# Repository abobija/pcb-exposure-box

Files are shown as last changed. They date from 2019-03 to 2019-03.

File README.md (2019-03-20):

# pcb-exposure-box
PCB Exposure Box made of an old Scanner

When you set the timer (max 999 seconds) with UP/DOWN buttons and then press button START, micro-controller-unit (MCU) PIC16F84A will turn on light and start to countdown to zero. When timer comes to zero, MCU will turn off the light signaling via the piezzo speaker that exposure process is done.

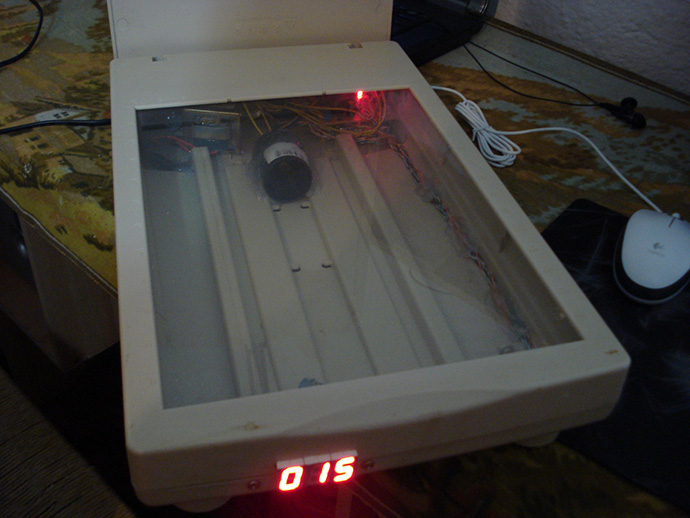
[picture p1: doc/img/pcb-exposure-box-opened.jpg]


# Video presentation

Click [here](https://www.youtube.com/watch?v=MrX0DLpo7UE) to watch short video presentation on YouTube.

_Video was recorded back in 2013 and quality of video is very bad (sorry about that)._

# Development Environment

- MCU used for realization of this project is PIC16F84A and software for them was written in C using (and compiled with) [mikroC environment](https://www.mikroe.com/mikroc-pic)
- PCBs were designed using the [Eagle](https://www.autodesk.com/products/eagle/overview)

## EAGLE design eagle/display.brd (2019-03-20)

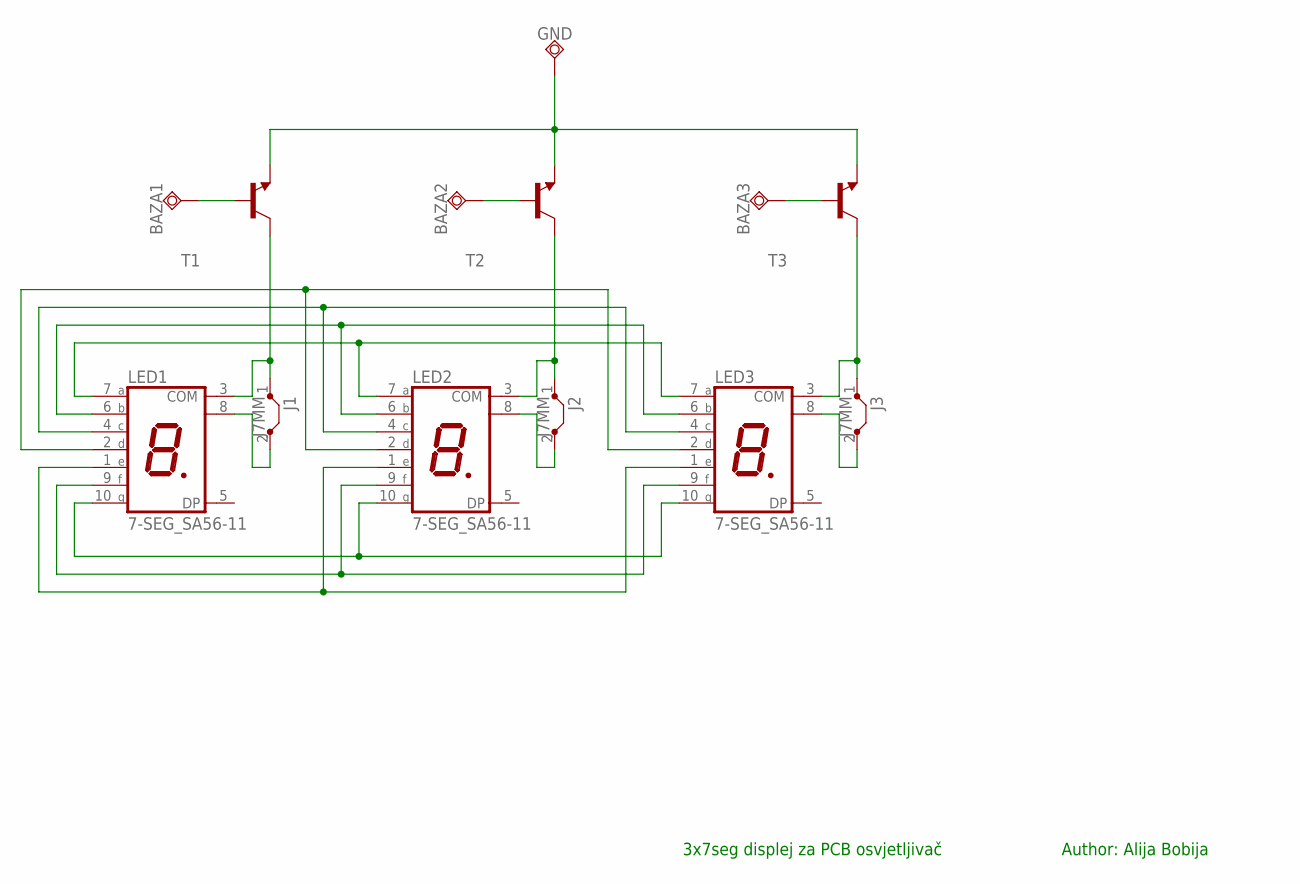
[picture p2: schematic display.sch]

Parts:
BAZA1, BAZA2, BAZA3: TPSQTP20SQ; TP20SQ
GND: TPSQTP20SQ; TP20SQ
J1, J2, J3: J7MM; 07
LED1, LED2, LED3: 7-SEG_SA56-11; SA56-11
T1, T2, T3: -NPN-SOT23-EBC; SOT23-EBC

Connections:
unnamed: LED1.7 (A), LED2.7 (A), LED3.7 (A)
unnamed: LED1.10 (G), LED2.10 (G), LED3.10 (G)
unnamed: LED1.6 (B), LED2.6 (B), LED3.6 (B)
unnamed: LED1.9 (F), LED2.9 (F), LED3.9 (F)
unnamed: LED1.4 (C), LED2.4 (C), LED3.4 (C)
unnamed: LED1.1 (E), LED2.1 (E), LED3.1 (E)
unnamed: LED1.2 (D), LED2.2 (D), LED3.2 (D)
unnamed: J1.1, LED1.3 (COM), T1.C
unnamed: J1.2, LED1.8 (COM)
unnamed: J2.1, LED2.3 (COM), T2.C
unnamed: J2.2, LED2.8 (COM)
unnamed: J3.1, LED3.3 (COM), T3.C
unnamed: J3.2, LED3.8 (COM)
unnamed: BAZA1.TP, T1.B
unnamed: BAZA2.TP, T2.B
unnamed: BAZA3.TP, T3.B
unnamed: GND.TP, T1.E, T2.E, T3.E

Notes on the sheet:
Author: Alija Bobija
3x7seg displej za PCB osvjetljivač

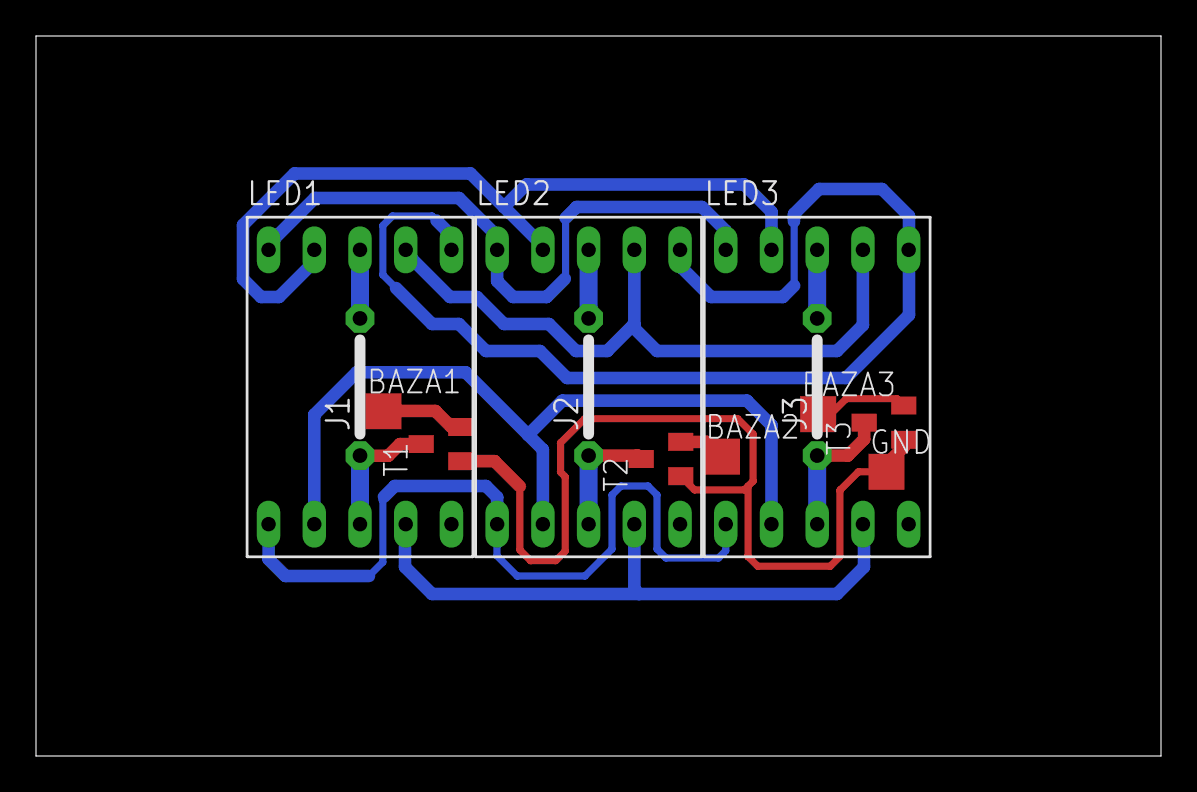
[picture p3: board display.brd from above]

Board: 2 copper layers, 62.5 x 40.0 mm, 13 parts (0 on the bottom side), 17 nets.

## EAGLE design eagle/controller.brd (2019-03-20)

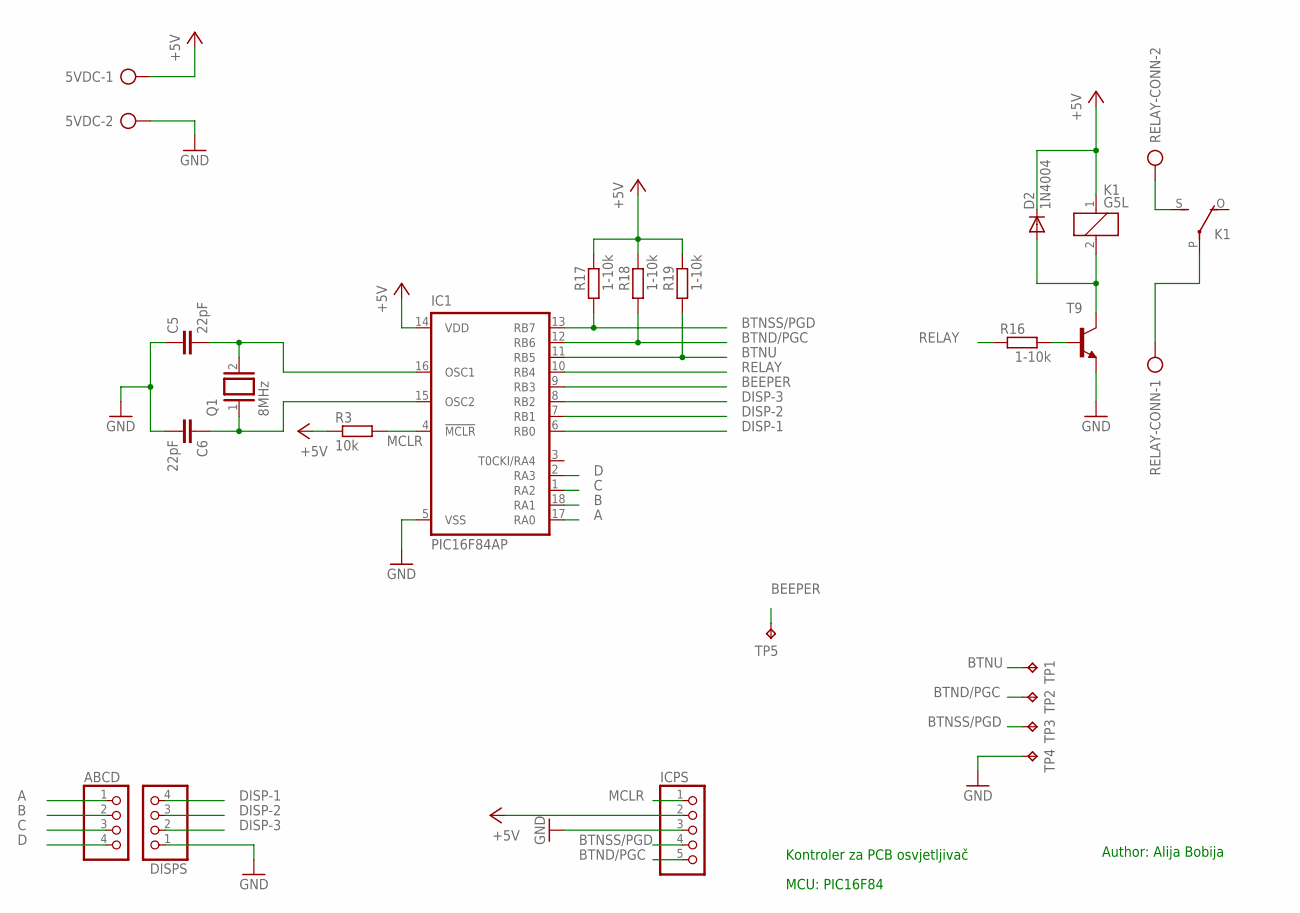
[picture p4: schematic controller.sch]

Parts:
5VDC: AK500/2
ABCD: PINHD-1X4; 1X04
C5, C6: 22pF; C025-024X044
D2: 1N4004; DO41-10
DISPS: PINHD-1X4; 1X04
IC1: PIC16F84AP; DIL18
ICPS: PINHD-1X5/90; 1X05/90
K1: G5L; G5LE
Q1: 8MHz; QS
R3: 10k; 0207/7
R16, R17, R18, R19: 1-10k; 0207/7
RELAY-CONN: AK500/2
T9: -NPN-SOT23-EBC; SOT23-EBC
TP1, TP2, TP3, TP4, TP5: TPTP15SQ; TP15SQ

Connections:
+5V: 5VDC.1, D2.C, IC1.14 (VDD), ICPS.2, K1.1, R3.1, R17.2, R18.2, R19.2
A: ABCD.1, IC1.17 (RA0)
B: ABCD.2, IC1.18 (RA1)
BEEPER: IC1.9 (RB3), TP5.TP
BTND/PGC: IC1.12 (RB6), ICPS.5, R18.1, TP2.TP
BTNSS/PGD: IC1.13 (RB7), ICPS.4, R17.1, TP3.TP
BTNU: IC1.11 (RB5), R19.1, TP1.TP
C: ABCD.3, IC1.1 (RA2)
D: ABCD.4, IC1.2 (RA3)
DISP-1: DISPS.4, IC1.6 (RB0)
DISP-2: DISPS.3, IC1.7 (RB1)
DISP-3: DISPS.2, IC1.8 (RB2)
GND: 5VDC.2, C5.1, C6.2, DISPS.1, IC1.5 (VSS), ICPS.3, T9.E, TP4.TP
MCLR: IC1.4 (!MCLR), ICPS.1, R3.2
unnamed: C5.2, IC1.16 (OSC1), Q1.2
unnamed: C6.1, IC1.15 (OSC2), Q1.1
unnamed: K1.S, RELAY-CONN.2
unnamed: D2.A, K1.2, T9.C
unnamed: R16.2, T9.B
unnamed: K1.P, RELAY-CONN.1
RELAY: IC1.10 (RB4), R16.1

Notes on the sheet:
Kontroler za PCB osvjetljivač
MCU: PIC16F84
Author: Alija Bobija

Board: 2 copper layers, 22 parts (0 on the bottom side), 21 nets, no tracks yet.

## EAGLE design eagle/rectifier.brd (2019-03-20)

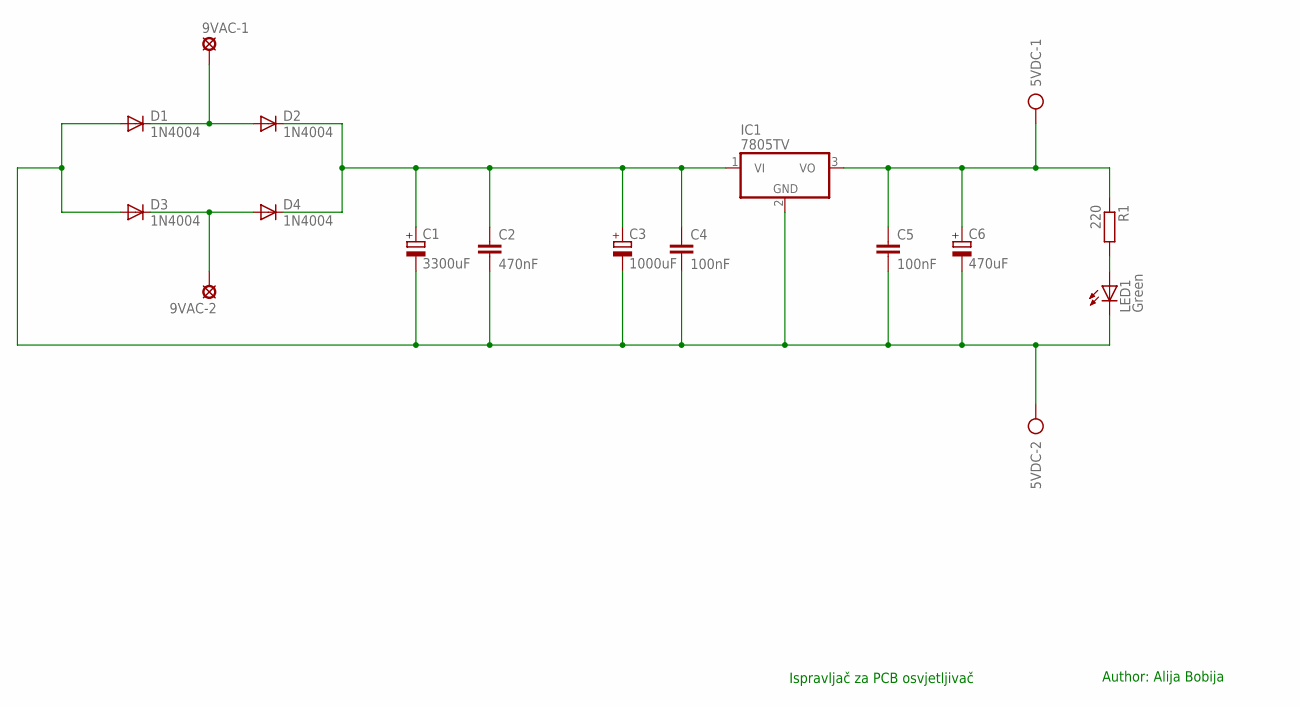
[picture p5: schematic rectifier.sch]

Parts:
5VDC: AK500/2
9VAC-1, 9VAC-2: LSP10
C1: 3300uF; E5-13
C2: 470nF; C050-024X044
C3: 1000uF; E3,5-10
C4, C5: 100nF; C025-024X044
C6: 470uF; E3,5-8
D1, D2, D3, D4: 1N4004; DO41-10
IC1: 7805TV; TO220V
LED1: Green; LED3MM
R1: 220; M0805

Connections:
GND: 5VDC.2, C1.-, C2.2, C3.-, C4.2, C5.2, C6.-, D1.A, D3.A, IC1.2 (GND), LED1.K (C)
unnamed: 9VAC-1.MP, D1.C, D2.A
unnamed: 9VAC-2.MP, D3.C, D4.A
unnamed: C1.+, C2.1, C3.+, C4.1, D2.C, D4.C, IC1.1 (VI)
unnamed: 5VDC.1, C5.1, C6.+, IC1.3 (VO), R1.1
unnamed: LED1.A, R1.2

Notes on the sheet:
Author: Alija Bobija
Ispravljač za PCB osvjetljivač

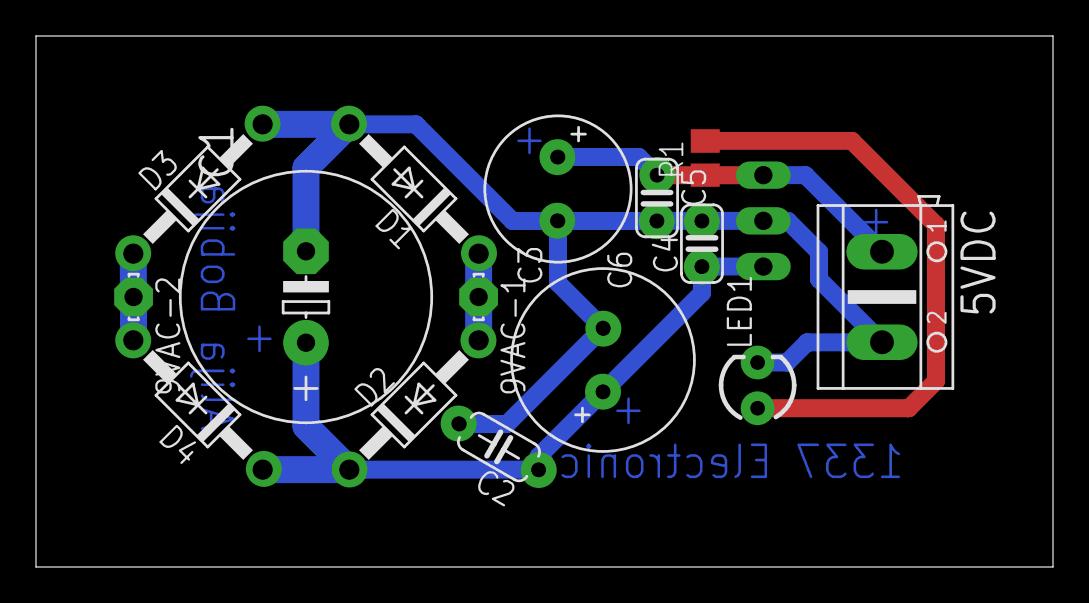
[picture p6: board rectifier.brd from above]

Board: 2 copper layers, 56.5 x 29.5 mm, 16 parts (1 on the bottom side), 6 nets.

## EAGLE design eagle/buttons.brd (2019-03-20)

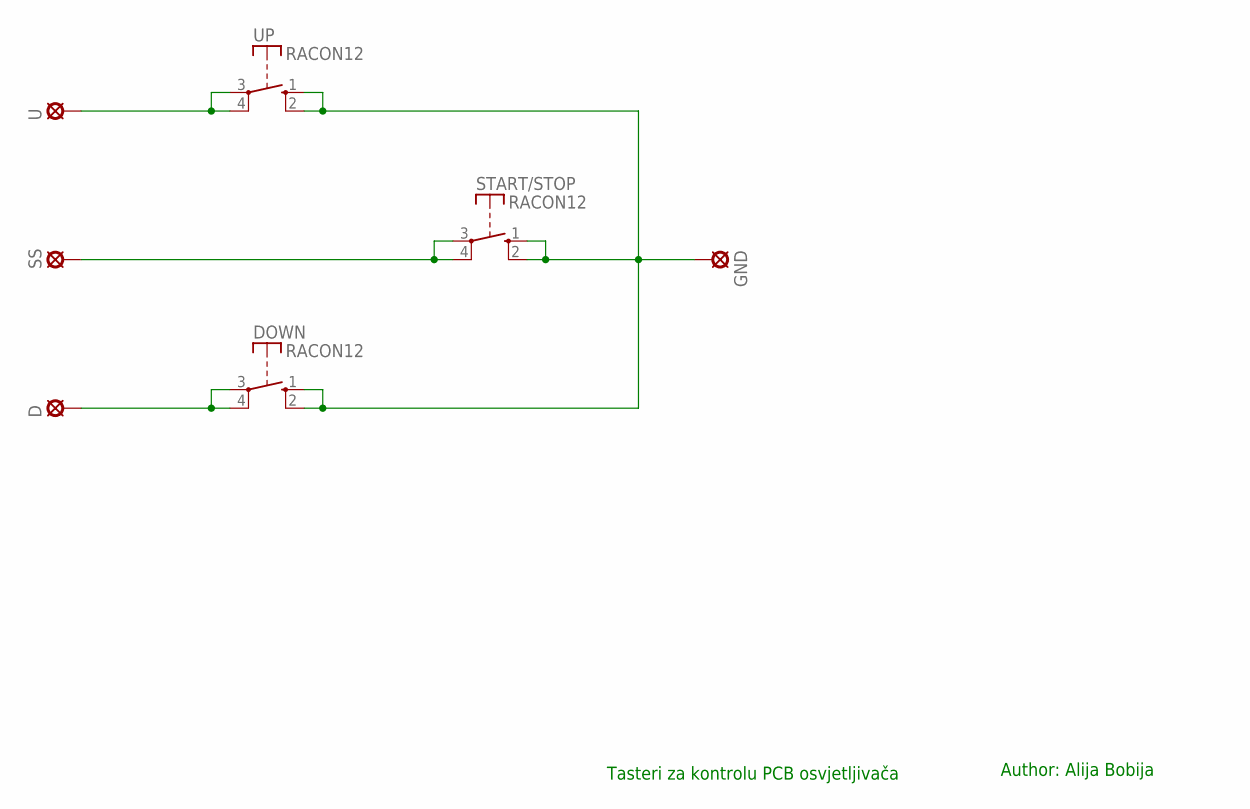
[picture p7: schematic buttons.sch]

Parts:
D: SE11
DOWN: RACON12
GND: SE11
SS: SE11
START/STOP: RACON12
U: SE11
UP: RACON12

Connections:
unnamed: DOWN.1 (S), DOWN.2 (S), GND.MP, START/STOP.1 (S), START/STOP.2 (S), UP.1 (S), UP.2 (S)
unnamed: U.MP, UP.3, UP.4
unnamed: D.MP, DOWN.3, DOWN.4
unnamed: SS.MP, START/STOP.3, START/STOP.4

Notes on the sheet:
Author: Alija Bobija
Tasteri za kontrolu PCB osvjetljivača

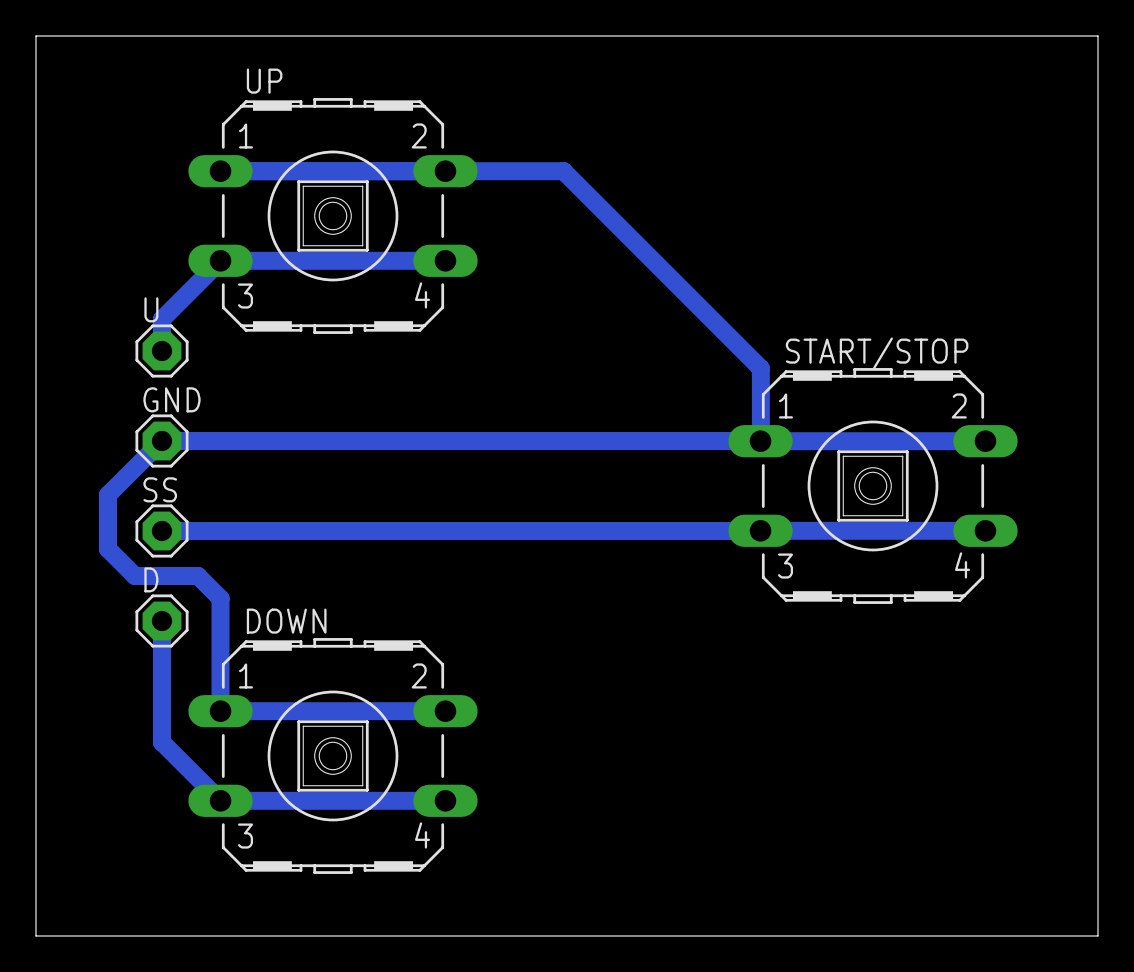
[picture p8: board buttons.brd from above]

Board: 2 copper layers, 59.0 x 50.0 mm, 7 parts (0 on the bottom side), 4 nets.

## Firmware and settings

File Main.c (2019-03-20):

#define DEBUG // Uncomment for "ISIS Proteus" sim, multiplex time reducing

#include "TypeDefs.h"
#include "Main.h"
#include "Timer.h"
#include "Buttons.h"

void interrupt()
{
  TMR0IF_bit = 0;
  TMR0 = Tmr0InitVal;
    
  if(++Tmr0OverflowCounter >= NOTmr0OverflowsReq4OneSec)
  {
    Tmr0OverflowCounter = 0;
    // One second tick
      
    if(TimerRunning)
    {
      DecrementTimer();
        
      if( IsZero() )
      {
        TimerRunning = false;
        TurnOffBulb();
        BulbTurnedOffInInterrupt = true;
      }
    }
    
    if(Piezo)
    {
      Mute();
    }
      
    // End of one second tick
  }
    
  #ifdef DEBUG
  if(Tmr0OverflowCounter % 50 == 0)
  {
  #endif
  // Multiplexing
    MultiplexDisplays();
  // End of multiplexing
  #ifdef DEBUG
  }
  #endif
}

void main() 
{
  PORTA = 0x00;
  PORTB = 0x00;
  TRISA = 0x00;
  TRISB = 0b11100000;

  InitTimer0();
  
  FillTimerWithDataFromEE();
  
  while(true)
  {
     // Buttons debouncing
     for(ButtonIndex = 0; ButtonIndex < 3; ButtonIndex++)
     {
       if(! ((PORTB >> (5 + ButtonIndex)) & 0x01) )
       {
         Buttons[ButtonIndex].PressedDebounceCounter++;
         Buttons[ButtonIndex].ReleasedDebounceCounter = 0;
         if(Buttons[ButtonIndex].PressedDebounceCounter >= SatisfyingDebounceCounter)
         {
           if(Buttons[ButtonIndex].Pressed)
           {
              // Ignore STOP/START (ButtonIndex 2) for long press
             if(ButtonIndex != 2 && ++Buttons[ButtonIndex].PressedCounter >= LongPressThreshold)
             {
               Buttons[ButtonIndex].PressedCounter = LongPressThreshold;
               Buttons[ButtonIndex].Event();
             }
           }
           else
           {
             Buttons[ButtonIndex].Pressed = true;
             Buttons[ButtonIndex].PressedCounter = 0;
             Buttons[ButtonIndex].Event();
           }

           Buttons[ButtonIndex].PressedDebounceCounter = 0;
         }
       }
       else
       {
         Buttons[ButtonIndex].ReleasedDebounceCounter++;
         Buttons[ButtonIndex].PressedDebounceCounter = 0;
         if(Buttons[ButtonIndex].ReleasedDebounceCounter >= SatisfyingDebounceCounter)
         {
           Buttons[ButtonIndex].Pressed = false;
           Buttons[ButtonIndex].ReleasedDebounceCounter = 0;
         }
       }
     }
     // End of button debouncing
     
     if(BulbTurnedOffInInterrupt)
     {
       BulbTurnedOffInInterrupt = false;
       FillTimerWithDataFromEE();
       Beep(); // Muted in interrupt after one second
     }
  }
}

// Button events

void ButtonUpEvent()
{
  if(! TimerRunning)
  {
    IncrementTimer();
  }
}

void ButtonDownEvent()
{
  if(! TimerRunning)
  {
    DecrementTimer();
  }
}

void ButtonStartStopEvent()
{
  if(TimerRunning)
  {
    TimerRunning = false;
    TurnOffBulb();
  }
  else
  {
    if(! IsZero())
    {
      SaveTimerDataInEE();

      TMR0 = Tmr0InitVal;
      Tmr0OverflowCounter = 0;
      TimerRunning = true;
      TurnOnBulb();
    }
  }
}

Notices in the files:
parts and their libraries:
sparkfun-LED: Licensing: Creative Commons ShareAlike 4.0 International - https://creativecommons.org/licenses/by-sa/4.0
